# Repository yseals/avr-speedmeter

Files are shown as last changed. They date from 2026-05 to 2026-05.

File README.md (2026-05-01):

# avr-speedmeter
プログラマー5年目(2009年頃)のときの製作物です

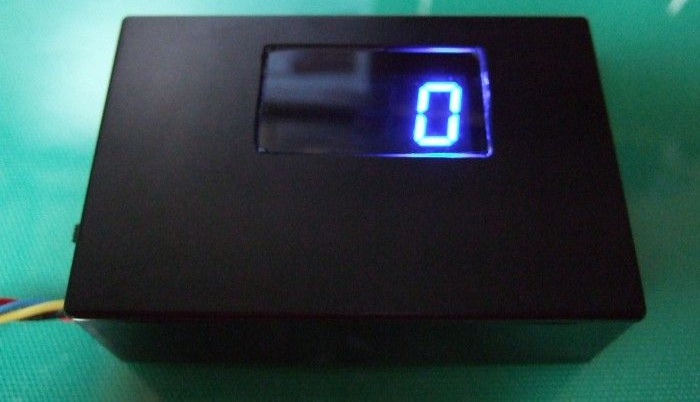
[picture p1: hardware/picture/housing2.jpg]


## 概要
ATTiny2313を使ったデジタルスピードメーターで<br>
ヘッドアップディスプレイ(HUD)として使用も可能です。<br>
車速パルスを拾い、7セグLEDでスピード表示します。

## 動作環境
2009年当時の環境で開発
- ATTiny2313 10MHzで動作
- AVR Studio4
- WinAVR

## 背景
乗っていた車にHUDつけたいなと思ったのがきっかけで作りました。<br>
回路基板製作もやってみたかったので、Eagle（CAD）使って、<br>
回路図作り、最終的にはガーバーデータまで作成し、基板屋さんへ基板製作依頼しました。

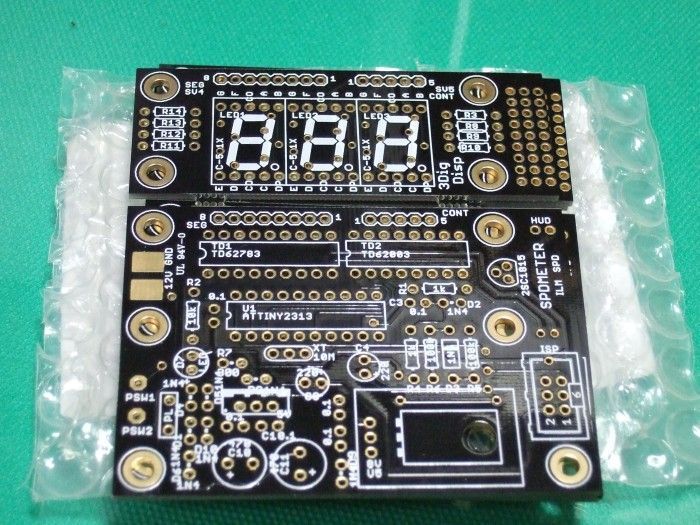
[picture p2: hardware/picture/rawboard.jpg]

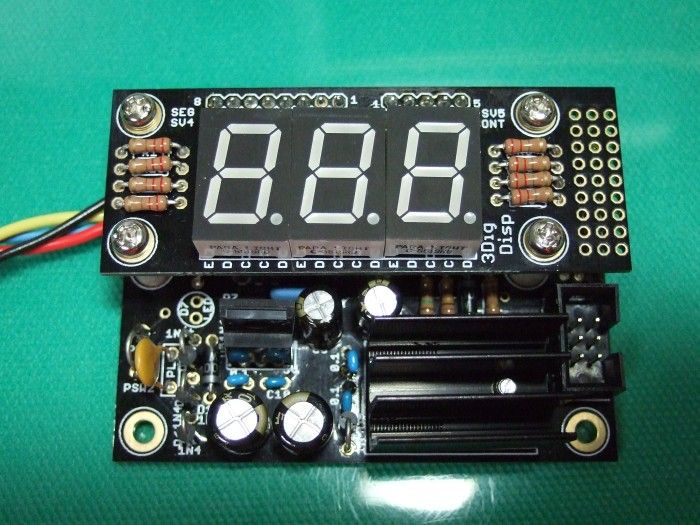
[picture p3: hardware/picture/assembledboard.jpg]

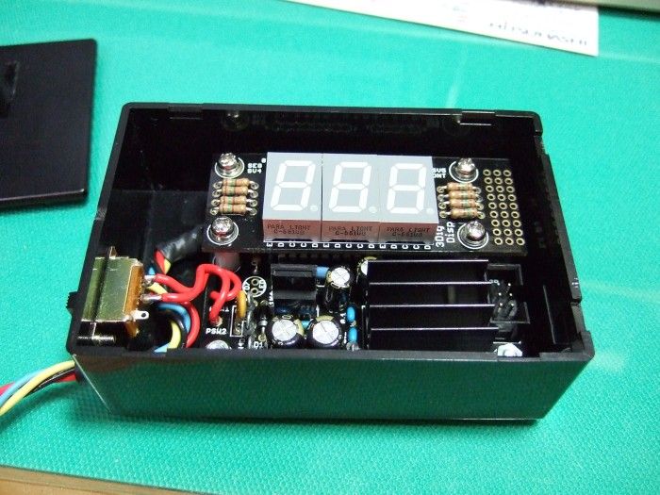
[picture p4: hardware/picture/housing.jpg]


## 使用方法
1. AVRマイコンにヒューズ設定.txtの内容を書き込んでください

1. main.hの設定を調整します
   | 設定項目 | 設定内容 |
   | --- | --- |
   | MISEC | define定義無しの場合、100us単位で調整可能、<br> define定義ありの場合1ms単位で設定可能 |
   | DISPLAY_CHG_TIME_HUD | HUDモードかつヘッドライトOFF時の7セグ1桁への出力時間 |
   | DISPLAY_OFF_TIME_HUD | HUDモードかつヘッドライトOFF時の7セグ1桁への出力OFF時間<br> 出力時間のうちOFFする時間設定し減光させる |
   | DISPLAY_CHG_TIME_ILUM_HUD | HUDモードかつヘッドライトON時の7セグ1桁への出力時間 |
   | DISPLAY_OFF_TIME_ILUM_HUD | HUDモードかつヘッドライトON時の7セグ1桁への出力OFF時間<br> 出力時間のうちOFFする時間設定し減光させる |
   | COUNTER_TIME | 車速パルスの測定周期かつ、スピード表示の更新周期<br>MES_COUNT x COUNTER_TIMEで1.4秒の値になるように設定する<br>1km/hが車速パルスで0.7Hzほどの周期のため |
   | ILUMI_TIME | イルミネーションON/OFFチェック周期 |
   | HUD_TIME | 起動時のHUDジャンパー確認までの待機時間 |
   | INITIAL_ON_TIME | 起動時の7セグ点灯チェックの点灯時間 |
   | INITIAL_OFF_TIME | 起動時の7セグ点灯チェック終了後の待機時間 |
   | MES_COUNT | 車速パルス測定回数、COUNTER_TIMEと合わせて設定<br>COUNTER_TIMEを伸ばすと、表示更新が遅くなるので、<br>MES_COUNTと組み合わせて更新間隔と測定時間を調整用 |
   | DISP_DIGIT | 固定値 3桁であることを設定（変更禁止） |
   | DISP_VALUE_NULL | 固定値 10とすることで7セグ非表示としてる（変更禁止） |

1. マイコンに書き込んで動作させてください

## 注意事項
- 本回路図は動作確認済みですが、製作・接続は自己責任で行ってください。

- 車など外部機器との接続により生じた破損や事故について、制作者は一切の責任を負いません。

## ライセンス
This software is released under the MIT License, see LICENSE.

## 作者
yseals

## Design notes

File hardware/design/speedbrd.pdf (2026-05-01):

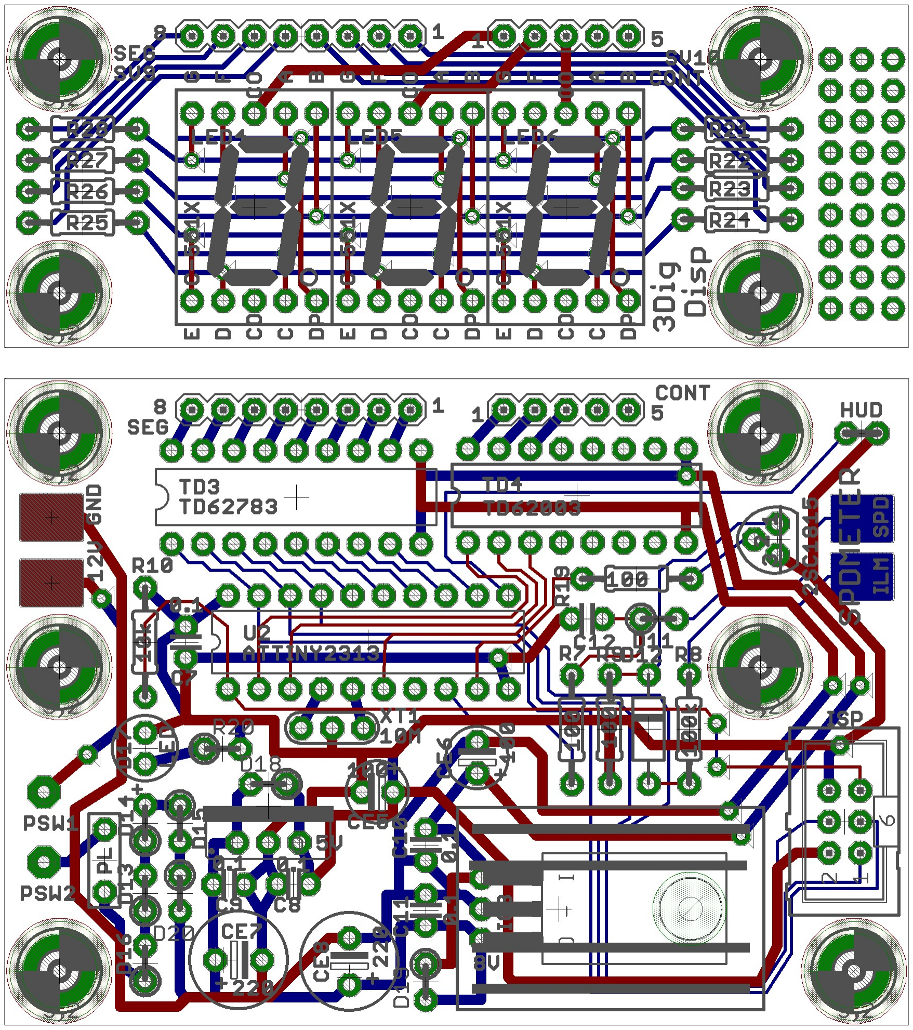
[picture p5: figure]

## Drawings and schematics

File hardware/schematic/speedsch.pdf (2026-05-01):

SV8 2 | 1 4 | 3 6 | 5 | D¹⁷

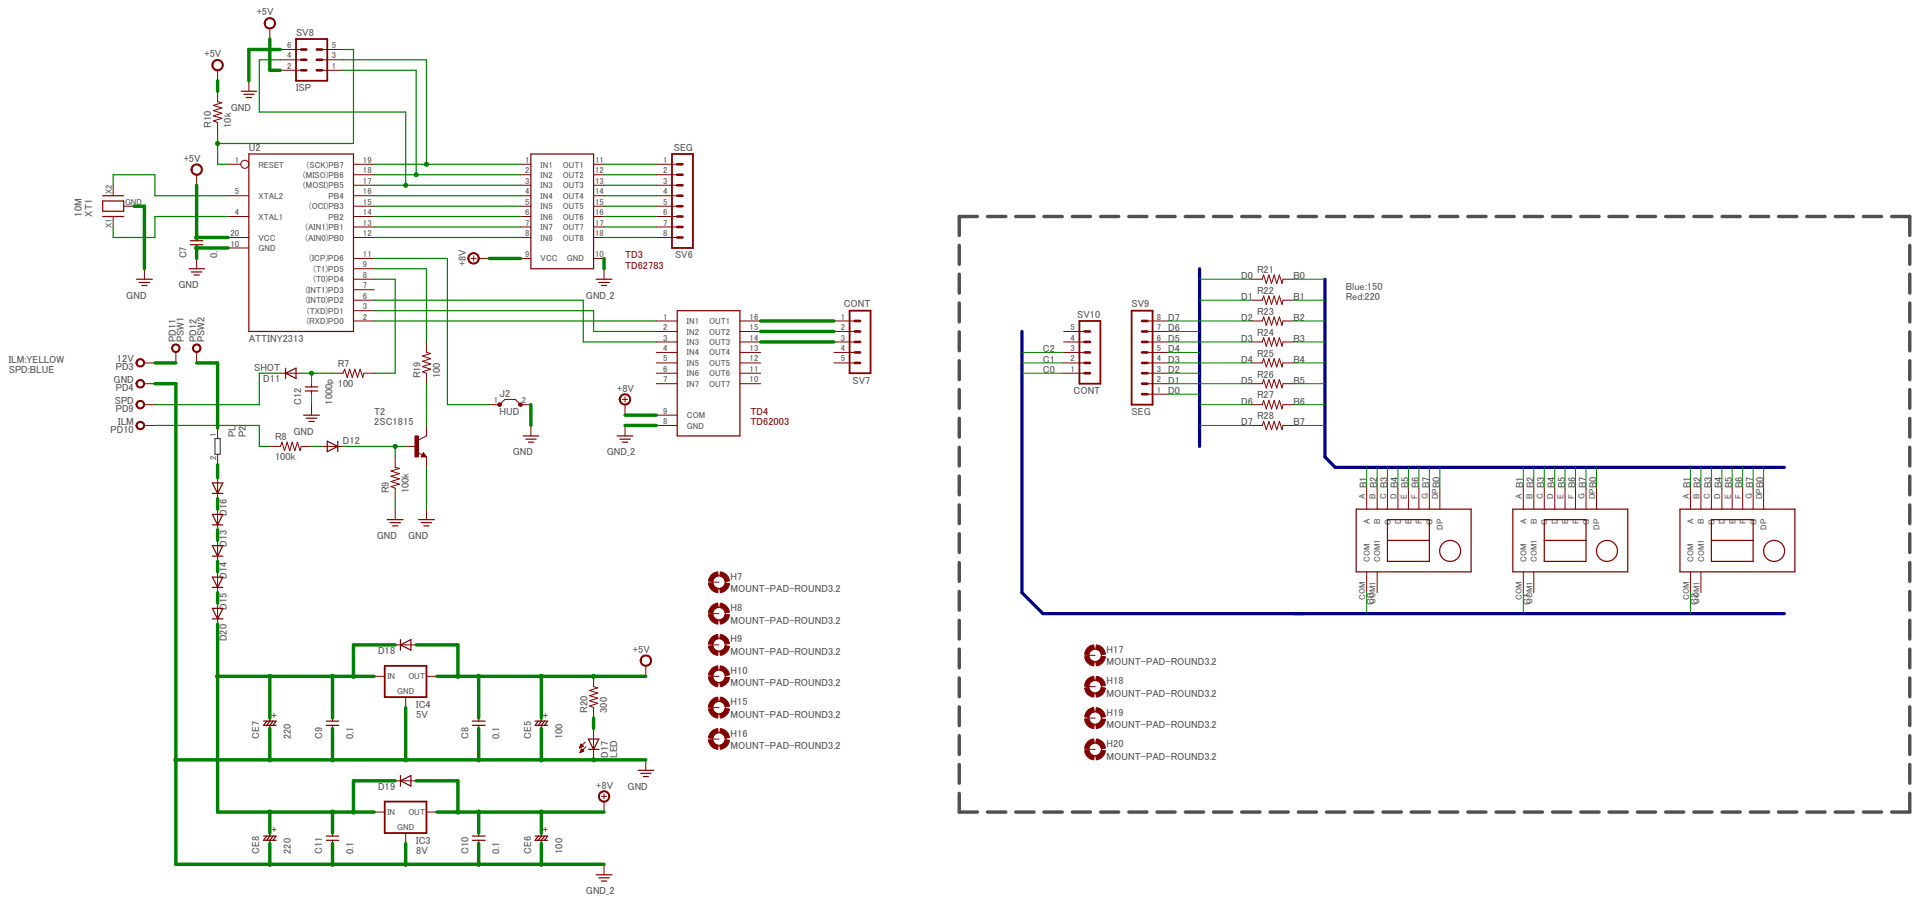
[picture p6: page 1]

CE7 CE8 E E D D F F C C G G B B DP DP A A COM COM COM1 COM1 E E D D F F C C G G B B DP DP A A COM COM COM1 COM1 E E D D F F C C G G B B DP DP A A COM COM COM1 COM1

MOUNT-PAD-ROUND3.2 MOUNT-PAD-ROUND3.2

MOUNT-PAD-ROUND3.2

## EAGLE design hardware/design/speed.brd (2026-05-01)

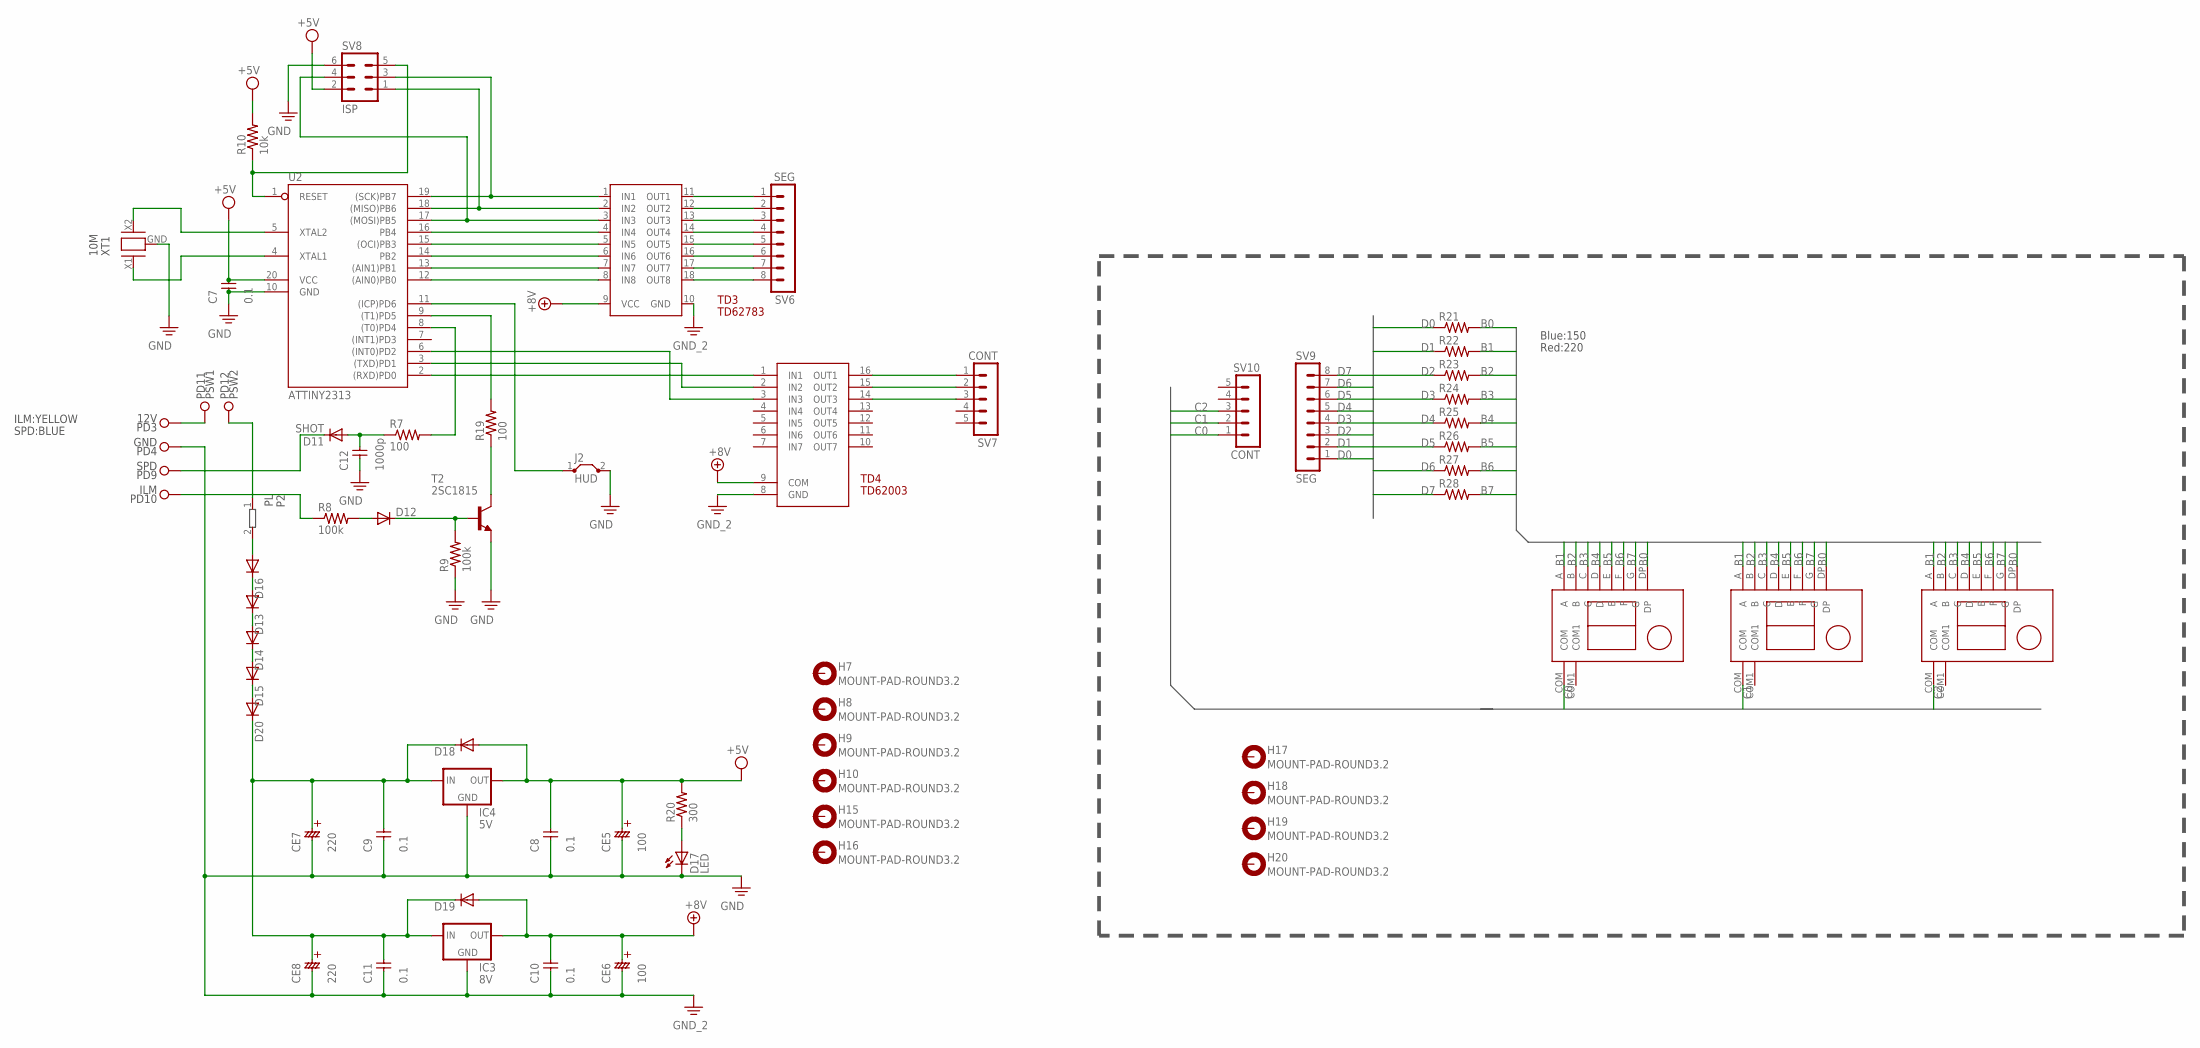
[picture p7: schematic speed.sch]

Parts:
C7, C8, C9, C10, C11: 0.1; C-2,5
C12: 1000p; C-2,5
CE5, CE6: 100; ELC-2,5
CE7, CE8: 220; ELC-5
D11: SHOT; 0204V
D12: 1N4004"; DIP-2-10
D13, D14, D15, D16, D18, D19, D20: 1N4004T; 0204V
D17: LED; LED5MM
H7, H8, H9, H10, H15, H16, H17, H18, H19, H20: MOUNT-PAD-ROUND3.2; 3,2-PAD
IC3: 8V; 78XXL
IC4: 5V; 78XXS
J2: HUD; JUMP2
LED4, LED5, LED6: C-551X; 7SEG-0.56
P2: PL; 0204/5
PD3: 12V; CFPAD
PD4: GND; CFPAD
PD9: SPD; CFPAD
PD10: ILM; CFPAD
PD11: PSW1; CPPAD
PD12: PSW2; CPPAD
R7, R19: 100; 0204/7
R8, R9: 100k; 0204/7
R10: 10k; 0204/7
R20: 300; 0204V
R21, R22, R23, R24, R25, R26, R27, R28: RES7; 0204/7
SV6, SV9: SEG; MA08-1
SV7, SV10: CONT; MA05-1
SV8: ISP; ML6
T2: 2SC1815; TO92
TD3: TD62783; DIP-18
TD4: TD62003; DIP-16
U2: ATTINY2313; DIP-20
XT1: 10M; CELALOCK

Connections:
+5V/1: C7.2, C8.2, CE5.PLUS, D18.1 (A), IC4.OUT, R10.2, R20.2, SV8.2, U2.20 (VCC)
+9V: C10.2, CE6.PLUS, D19.1 (A), IC3.IN (OUT), TD3.9 (VCC), TD4.9 (COM)
B0: LED4.DP, LED5.DP, LED6.DP, R21.2
B1: LED4.A, LED5.A, LED6.A, R22.2
B2: LED4.B, LED5.B, LED6.B, R23.2
B3: LED4.C, LED5.C, LED6.C, R24.2
B4: LED4.D, LED5.D, LED6.D, R25.2
B5: LED4.E, LED5.E, LED6.E, R26.2
B6: LED4.F, LED5.F, LED6.F, R27.2
B7: LED4.G, LED5.G, LED6.G, R28.2
C0: LED4.COM, SV10.1
C1: LED5.COM, SV10.2
C2: LED6.COM, SV10.3
D0: R21.1, SV9.1
D1: R22.1, SV9.2
D2: R23.1, SV9.3
D3: R24.1, SV9.4
D4: R25.1, SV9.5
D5: R26.1, SV9.6
D6: R27.1, SV9.7
D7: R28.1, SV9.8
unnamed: R10.1, SV8.5, U2.1 (RESET)
unnamed: SV8.3, TD3.1 (IN1), U2.19 ((SCK)PB7)
unnamed: SV8.1, TD3.2 (IN2), U2.18 ((MISO)PB6)
unnamed: SV8.4, TD3.3 (IN3), U2.17 ((MOSI)PB5)
unnamed: TD3.4 (IN4), U2.16 (PB4)
unnamed: TD3.5 (IN5), U2.15 ((OCI)PB3)
unnamed: TD3.6 (IN6), U2.14 (PB2)
unnamed: TD3.7 (IN7), U2.13 ((AIN1)PB1)
unnamed: R7.2, U2.8 ((T0)PD4)
unnamed: J2.1, U2.11 ((ICP)PD6)
unnamed: C12.2, D11.1 (A), R7.1
unnamed: D11.2 (C), PD9.CPAD
unnamed: D12.A, R8.2
unnamed: PD10.CPAD, R8.1
unnamed: U2.5 (XTAL2), XT1.X2
unnamed: U2.4 (XTAL1), XT1.X1
unnamed: R19.2, U2.9 ((T1)PD5)
unnamed: TD3.8 (IN8), U2.12 ((AIN0)PB0)
unnamed: TD4.1 (IN1), U2.2 ((RXD)PD0)
unnamed: TD4.2 (IN2), U2.3 ((TXD)PD1)
unnamed: TD4.3 (IN3), U2.6 ((INT0)PD2)
unnamed: SV7.1, TD4.16 (OUT1)
unnamed: SV7.2, TD4.15 (OUT2)
unnamed: SV7.3, TD4.14 (OUT3)
unnamed: C9.2, C11.2, CE7.PLUS, CE8.PLUS, D18.2 (C), D19.2 (C), D20.2 (C), IC3.OUT (IN), IC4.IN
unnamed: D12.C, R9.2, T2.1 (B)
unnamed: P2.1, PD12.CPPAD
unnamed: PD3.CPAD, PD11.CPPAD
unnamed: SV6.1, TD3.11 (OUT1)
unnamed: SV6.2, TD3.12 (OUT2)
unnamed: SV6.3, TD3.13 (OUT3)
unnamed: SV6.4, TD3.14 (OUT4)
unnamed: SV6.5, TD3.15 (OUT5)
unnamed: SV6.6, TD3.16 (OUT6)
unnamed: SV6.7, TD3.17 (OUT7)
unnamed: SV6.8, TD3.18 (OUT8)
unnamed: D16.1 (A), P2.2
unnamed: D13.1 (A), D16.2 (C)
unnamed: D13.2 (C), D14.1 (A)
unnamed: D14.2 (C), D15.1 (A)
unnamed: R19.1, T2.2 (C)
unnamed: D17.A, R20.1
unnamed: D15.2 (C), D20.1 (A)
PE: C7.1, C8.1, C9.1, C10.1, C11.1, C12.1, CE5.MAINAS, CE6.MAINAS, CE7.MAINAS, CE8.MAINAS, D17.K (C), IC3.GND, IC4.GND, J2.2, PD4.CPAD, R9.1, SV8.6, T2.3 (E), TD3.10 (GND), TD4.8 (GND), U2.10 (GND), XT1.GND

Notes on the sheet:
Blue:150
Red:220
ILM:YELLOW
SPD:BLUE

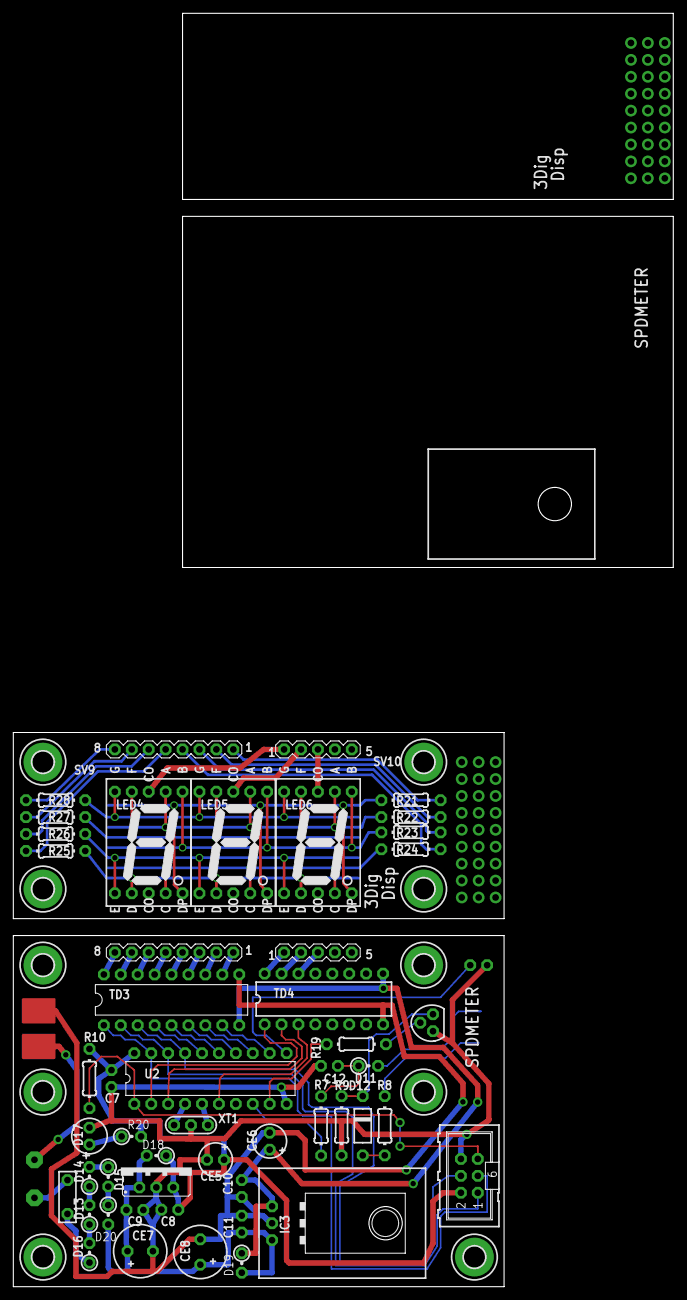
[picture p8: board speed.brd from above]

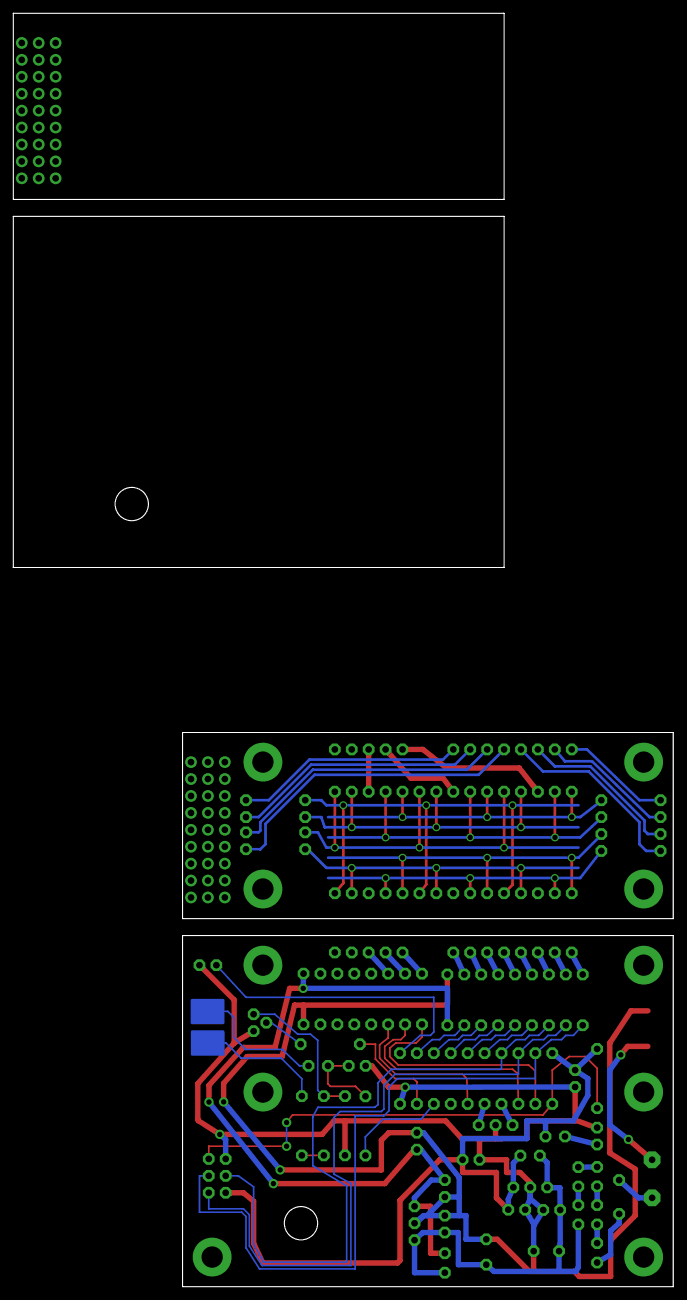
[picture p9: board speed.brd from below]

Board: 2 copper layers, 99.1 x 191.1 mm, 69 parts (2 on the bottom side), 65 nets.

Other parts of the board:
U$1, U$2: TO-220HEATSINKN

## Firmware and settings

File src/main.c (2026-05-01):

#include <avr/io.h>
#include <avr/interrupt.h>
#include <avr/pgmspace.h>
#include <util/delay.h>
#include "main.h"



// 16bitタイマー比較一致割り込み処理 
ISR ( TIMER1_COMPA_vect )
{
	// カウンタ加算
	disp_chg++;
	disp_off++;
	countin++;
	ilmi_chk++;

	// 車速パルスカウント
	if(countin >= COUNTER_TIME){
		countin = 0;
		isr_spplus_count();
	}

	// イルミネーションチェック
	if(ilmi_chk >= ILUMI_TIME){
		ilmi_chk = 0;
		isr_ilum_chk();
	}

	// 桁更新タイミング	
	if(disp_chg >= CHG_TIME){
		disp_chg = 0;
		disp_off = 0;
		isr_disp_chg();
	}

	// DISP_OFF時間になったら、もしくは設定時間が0の場合
	if((disp_off >= OFF_TIME) || (OFF_TIME == 0)){
		isr_disp_segment();
	}
}

// ディスプレイ表示
static void isr_disp_segment()
{
	// 表示桁が変更された場合のみ処理を行う
	if(disp_point_bef != disp_point){
		disp_point_bef = disp_point;

		// 指定桁の表示出力
		display_segment(disp_point, speed_value[disp_point]);
	}
}

// 桁変更
static void isr_disp_chg()
{
	// 更新初期化
	disp_point++;

	if(disp_point >= DISP_DIGIT){
		disp_point = 0;
	}

	// 桁切り替えの場合は表示をクリア
	display_clear();
}

// 車速パルスカウント
static void isr_spplus_count()
{
	uint8_t speed = 0;

	// パルスカウント数を取得
	mesdata[mespos] = TCNT0;

	// 8bitカウンタのカウント初期化（パルス数）
	TCNT0 = 0;

	mespos++;
	if(mespos == MES_COUNT){
		mespos = 0;
	}

	// スピード計算（MES_COUNT回分で1.4秒間の移動平均）
	for(uint8_t i = 0; i < MES_COUNT; i++){
		speed += mesdata[(int)i];
	}

	// 各桁に値を分離する
	calc_speed(speed);
}

// イルミネーションチェック
static void isr_ilum_chk()
{
	if(hud_on == HUD_FLG_ON){	// HUDバージョンの場合
		// D5の状態をチェック（イルミ状態）
		if((PIND & _BV(PIND5)) == 0){
			// イルミオンの場合の表示時間
			CHG_TIME = DISPLAY_CHG_TIME_ILUM_HUD;
			OFF_TIME = DISPLAY_OFF_TIME_ILUM_HUD;
		} else {
			// イルミオフの場合の表示時間
			CHG_TIME = DISPLAY_CHG_TIME_HUD;
			OFF_TIME = DISPLAY_OFF_TIME_HUD;
		}
	} else {
		// D5の状態をチェック（イルミ状態）
		if((PIND & _BV(PIND5)) == 0){
			// イルミオンの場合の表示時間
			CHG_TIME = DISPLAY_CHG_TIME_ILUM;
			OFF_TIME = DISPLAY_OFF_TIME_ILUM;
		} else {
			// イルミオフの場合の表示時間
			CHG_TIME = DISPLAY_CHG_TIME;
			OFF_TIME = DISPLAY_OFF_TIME;
		}
	}
}



/////////////////////////////////
// タイマー初期化処理
/////////////////////////////////
static void timer_init()
{
	// タイマー設定
	// 8bitタイマーをT0ピンよりの立ち下がりでカウント
	TCCR0B = _BV(CS02) | _BV(CS01);


	// 16bitタイマーをプリスケーラーなしでカウント
	// 比較Aで割り込み
	// CTC動作（割り込みが発生するとカウンタがリセットされる）
	TCCR1B = _BV(CS10) | _BV(WGM12);

	// 16bitタイマーの最大値を設定（1ms or 100usの設定）
	OCR1A = TIMER_OVF_COUNT;

	// 16bitタイマーの比較A許可
	TIMSK = _BV(OCIE1A);
}

/////////////////////////////////
// ポート初期化処理
/////////////////////////////////
static void port_init()
{

	// ウォッチドックタイマー停止
	WDTCSR = 0;


	// ポートの初期設定

	// プルアップ禁止
	MCUCR |= _BV(PUD);

	// アナログ比較機停止
	ACSR &= _BV(ACD);

	// B0～B7までを出力に(7seg用)
    PORTB = 0;
    DDRB  = 0b11111111;

	// D4を入力・プルアップ設定(パルス入力用)
	// D5を入力・プルアップ(イルミ入力用 イルミONでGNDに落ちる)
	// D0,D1,D2を出力（トランジスタ用）
  	// D6を入力・プルアップ設定（HUD設定の読み込み用）
	// D7は未使用なので設定しない
	PORTD = 0;
    DDRD  = 0b00001111;
    PORTD = 0b01110000;

	// プルアップ許可
	MCUCR &= ~_BV(PUD);

	// 少し待ってD6の状態を確認
	wait(HUD_TIME);
	if((PIND & _BV(PIND6)) == 0){
		// 接続(GNDに落ちる)の場合はHUDモード
		hud_on = HUD_FLG_ON;
	} else {
		// 未接続(HI)の場合は通常モード
		hud_on = HUD_FLG_OFF;
	}

	// プルアップ禁止
	MCUCR |= _BV(PUD);

	// チェックが終わったらD6端子は元に戻す(途中でHUDモードを変更しない為)
	// 先に出力設定(PORTD)をLにすること、そうしないと出力に設定時にHが出力され短絡の可能性がある
	PORTD &= ~_BV(PIND6);
	DDRD  |= _BV(PIND6);

	// プルアップ許可
	MCUCR &= ~_BV(PUD);

}



///////////////////
// 7segに表示する
///////////////////
static void display_segment(uint8_t p_cPoint, uint8_t disp_num)
{
	uint8_t value = 0;

	// 非表示対象の値の場合
	if(disp_num == DISP_VALUE_NULL){
		// 処理しない
		return;
	}

	if(hud_on == HUD_FLG_ON){
		// HUDモードの場合
		value = pgm_read_byte(&seg_num_b[disp_num]);
	} else {
		// 通常モードの場合
		value = pgm_read_byte(&seg_num[disp_num]);
	}

	// 数字に合わせた出力
	PORTB = value;

	if(p_cPoint == 0){
		// 100の位
		PORTD |= SEG100;
	} else if(p_cPoint == 1){
		// 10の位
		PORTD |= SEG010;
	} else if(p_cPoint == 2){
		// 1の位
		PORTD |= SEG001;
	} else {
		PORTD &= ~(_BV(PIND0) | _BV(PIND1) | _BV(PIND2));
	}
}

//////////////////
// 全表示クリア
//////////////////
static void display_clear()
{
	// 全LED出力をOFFします
	PORTB = 0;

	// 各トランジスタの出力をOFF
	PORTD &= ~(_BV(PIND0) | _BV(PIND1) | _BV(PIND2));
}

//////////////////
// 初期点灯チェック
//////////////////
static void initial_check()
{
	display_clear();

	display_segment(2, 8);
	wait(INITIAL_ON_TIME);

	display_clear();

	display_segment(1, 8);
	wait(INITIAL_ON_TIME);

	display_clear();

	display_segment(0, 8);
	wait(INITIAL_ON_TIME);

	display_clear();

	// 0表示とする
	speed_value[0] = DISP_VALUE_NULL;
	speed_value[1] = DISP_VALUE_NULL;
	speed_value[2] = 0;

	wait(INITIAL_OFF_TIME);
}

//////////////////
// スピード計算
//////////////////
static void calc_speed(uint8_t p_speed)
{
	uint8_t speed = p_speed;
	uint8_t tmp2 = 0;

	uint8_t find = 0;
	uint8_t tmp = 0;
	const uint8_t kurai[] = {100, 10, 1};

	// 各桁の数値を取得
	for(tmp2 = 0; tmp2 < DISP_DIGIT; tmp2++){
		tmp = 0;
		for(;;){
			if(speed < kurai[tmp2]){
				break;
			}
			tmp++;
			speed -= kurai[tmp2];
			find = 1;
		}
		
		if(find == 0){
			if(tmp2 == 2){
				// 1の位の場合は0でも表示する
				speed_value[tmp2] = tmp;
			} else{
				// 上位桁が0の場合は表示しない
				speed_value[tmp2] = DISP_VALUE_NULL;
			}
		} else {
			// 該当桁の数値を保持
			speed_value[tmp2] = tmp;
		}
	}
}

/////////////////////
// 処理待ち 1ms単位
/////////////////////
static void wait(uint16_t time)
{
	for(uint16_t i = 0; i < time; i++){
		_delay_ms(1);
	}
}

/////////////////////////////
// メイン関数
/////////////////////////////
int main(void)
{
	// 割り込み禁止
	cli();

	disp_chg = 0;
	disp_off = 0;
	countin = 0;
	disp_point = 0;
	disp_point_bef = 0;
	hud_on = 0;
	ilmi_chk = 0;
	CHG_TIME = DISPLAY_CHG_TIME;
	OFF_TIME = DISPLAY_OFF_TIME;

	// パルスデータ初期化
	for(mespos = 0; mespos < MES_COUNT; mespos++){
		mesdata[mespos] = 0;
	}

	mespos = 0;

	// ポート設定初期化
	port_init();

	// 初期点灯チェック
	initial_check();

	// タイマー初期化
	timer_init();

	// 全割り込み許可
	sei();

	// 終了待ち（無限待ち）
	for(;;){}

	return 0;
}

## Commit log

2026-04-30 README新規登録
    Added detailed setup and usage instructions for the digital speedometer project.
2026-04-30 README更新
    Updated README with additional setup and usage instructions.
2026-05-01 Create .gitattribute
    改行コードを変更しない設定
2026-05-01 初期バージョン
    初期バージョン登録
    [speed.brd, speed.sch]
